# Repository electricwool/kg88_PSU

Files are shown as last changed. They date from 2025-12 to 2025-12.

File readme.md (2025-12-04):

## Garter Carriage PSU

- fits a garter carriage power supply box and the stock speed control knob
- speed control knob works in reverse due to limitations of simple switching power supplies and difficulty working with the 1k potentiometer. you can move one of the pot wires to the other side to fix this if it's important to you.
- takes a 15V supply
- provides a greater range of speed than normal
- 2A efuse functions to provides overcurrent/overtorque safety shutoff
- on my unit white wire is positive, black wire is negative
- tested with KG88 and KG89

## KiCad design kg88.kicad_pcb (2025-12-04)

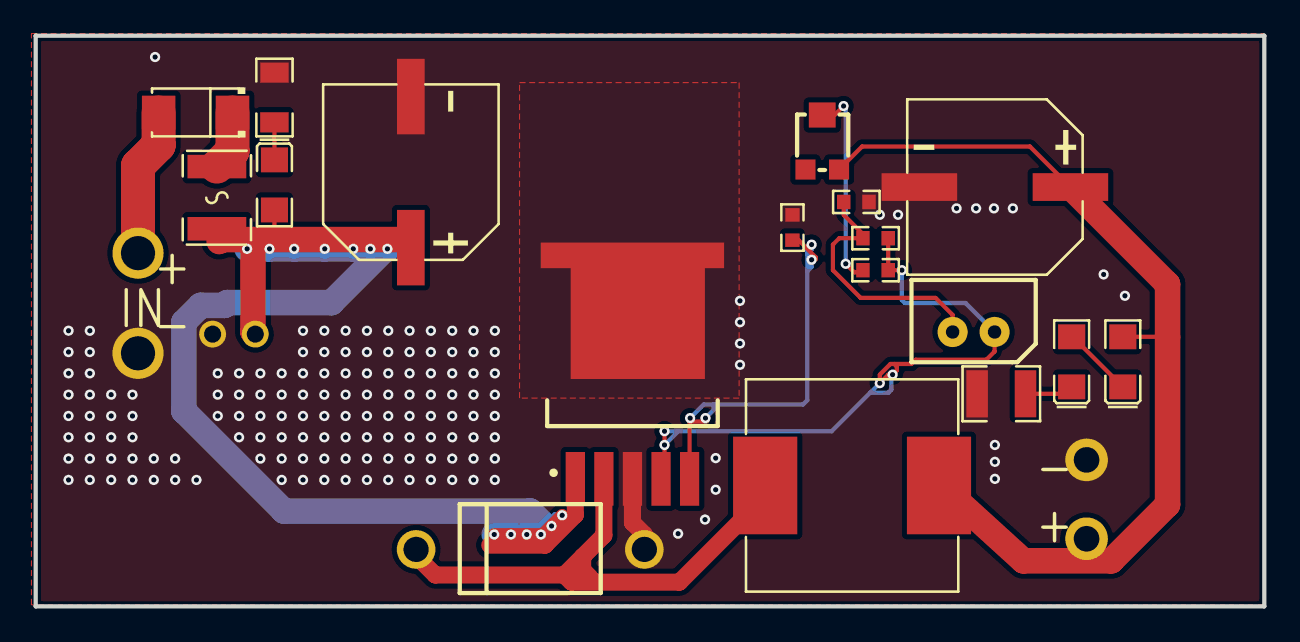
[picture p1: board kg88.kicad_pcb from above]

Board: 2 copper layers, 73.2 x 34.0 mm, 18 parts (0 on the bottom side), 12 nets.

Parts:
1N5824: DO-27_BD5.3-L8.4-P12.40-D1.3-RD
68mH: IND-SMD_L12.5-W12.5
C1, C2: CAP-SMD_BD10.0-L10.3-W10.3-FD
CN1: CONN-TH_5267-02A
D1: SMA_L4.3-W2.6-LS5.2-RD
F1: F1812
LED1, LED2, LED3: LED1206-R-RD_GREEN
R1, R2, R3, R4: R0603
R5: R1206
R6: R1210
R7: RES-ADJ-SMD_JER33X-1-14
U2: TO-263-5_L10.2-W8.9-P1.70-TL

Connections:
$1N915: 1N5824.1, 68mH.1, U2.2
$1N1180: CN1.1, R2.2, R4.2, U2.4
$1N1219: CN1.2, R1.1, R4.1
$1N1297: R3.1, U2.5
$1N1694: LED1.2, R5.1
F1: D1.1, F1.2
GND: 1N5824.2, C1.2, C2.2, R1.2, R3.2, R5.2, R6.1, U2.3, U2.6
LED1: LED2.2, LED3.1
LED3: LED3.2, R6.2
TRIM: R2.1, R7.2
VIN: C2.1, F1.1, LED1.1, U2.1
VOUT: 68mH.2, C1.1, LED2.1, R7.1
